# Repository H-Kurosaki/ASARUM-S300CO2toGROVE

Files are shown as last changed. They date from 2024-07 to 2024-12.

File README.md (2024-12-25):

# ASARUM-S300CO2toGROVE
ELT社のCO2センサS-300をGroveコネクタに対応させる基板のデータを公開しています。
boardall

◯公開しているデータの内容

/main/GerberData

Grove化基板のガーバーデータ、FusionPCBのファイル名に準拠しています。このフォルダの内容をzipに圧縮すればそのまま発注に使えます。

/main/EagleBoard

Eagle形式のPCBデータ(GerberDataの元データ)

/main/EagleLbr

Eagle形式のライブラリS-300のフットプリント。背面のJ11,J12コネクタのみ配置してあります。おまけでK30のフットプリントも入っていますが検証していません。

/main/BOM

実装部品表

/main/ArduinoS300test

Arduino UNO R3を用いた場合のテストプログラム。I2C接続時の読み出し試験。

◯基板の仕様

S-300のI2CインターフェースをGroveケーブルで引き出すことができます。
S-300の裏側の2mmピッチコネクタを使用するので基板から簡単にセンサを着脱できる実装が行えます。
MCDL校正を行う場合は通電して起動後に10分間MCDLと書かれた部分のピンをジャンパーで短絡してください。
その他I2C以外のピンもよく使いそうなものはピンヘッダに出ています。

基板の穴の間隔は未来工業社のウォルボックスWB-DMシリーズなどの穴の位置に合わせてあります。

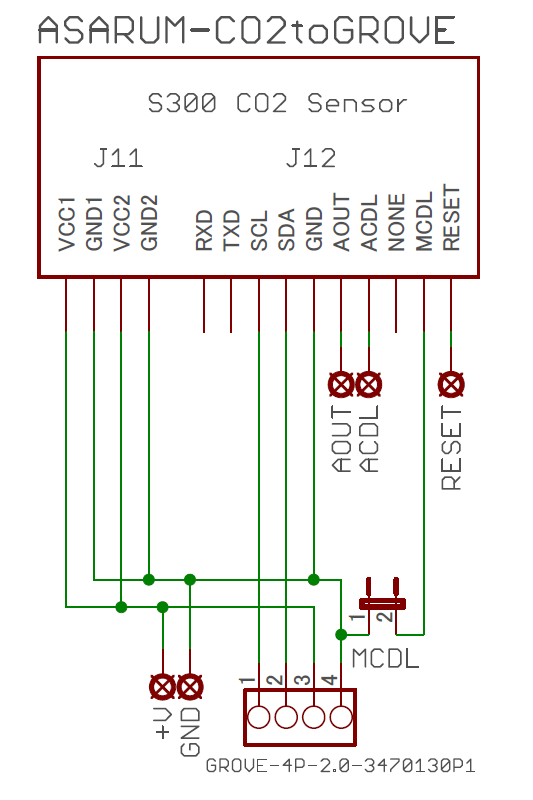
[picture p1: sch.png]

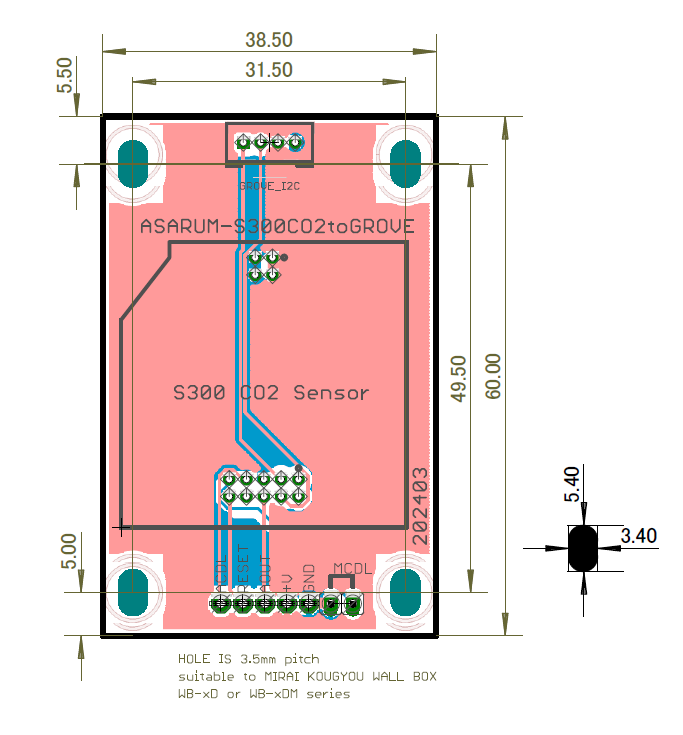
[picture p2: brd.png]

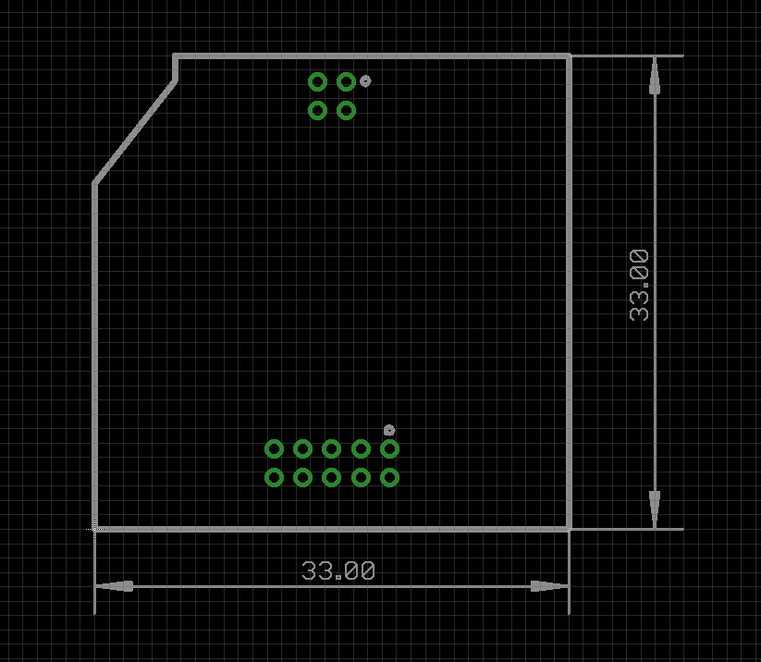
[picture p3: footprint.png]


◯使用上の注意とライセンス

本リポジトリで公開しているデータはELT社の公式なものではありません。
本リポジトリでライセンスを設定可能なファイルにはMITライセンスを適用させていただきます。
二次配布、商用利用も可能なデータとして配布しますが、本データを使用したことによって生じた結果については利用者が全ての責任を負うものとします。

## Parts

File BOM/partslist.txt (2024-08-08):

部品名	入手先	
Groveコネクター L型 スルーホール	https://akizukidenshi.com/catalog/g/g112634/	
コネクター付コード 4P 黒赤白黄 Grove用ケーブル	https://akizukidenshi.com/catalog/g/g116938/	
2mmピッチピンヘッダー 2×40 (80P)	https://akizukidenshi.com/catalog/g/g106075/	
ピンヘッダー 1×40 (40P)	https://akizukidenshi.com/catalog/g/g100167/	
つまみ付ジャンパーピン(黒)(2.54mmピッチ)	https://akizukidenshi.com/catalog/g/g103890/	(MCDL校正に使う)
		
※ピンヘッダは折って使います		
※Groveコネクターはスルーホール用であればL型(SEEED-110990037)も普通の直立型(SEEED-110990030)も両方使えます		
※ケーブルはあまり長くしないことを推奨します

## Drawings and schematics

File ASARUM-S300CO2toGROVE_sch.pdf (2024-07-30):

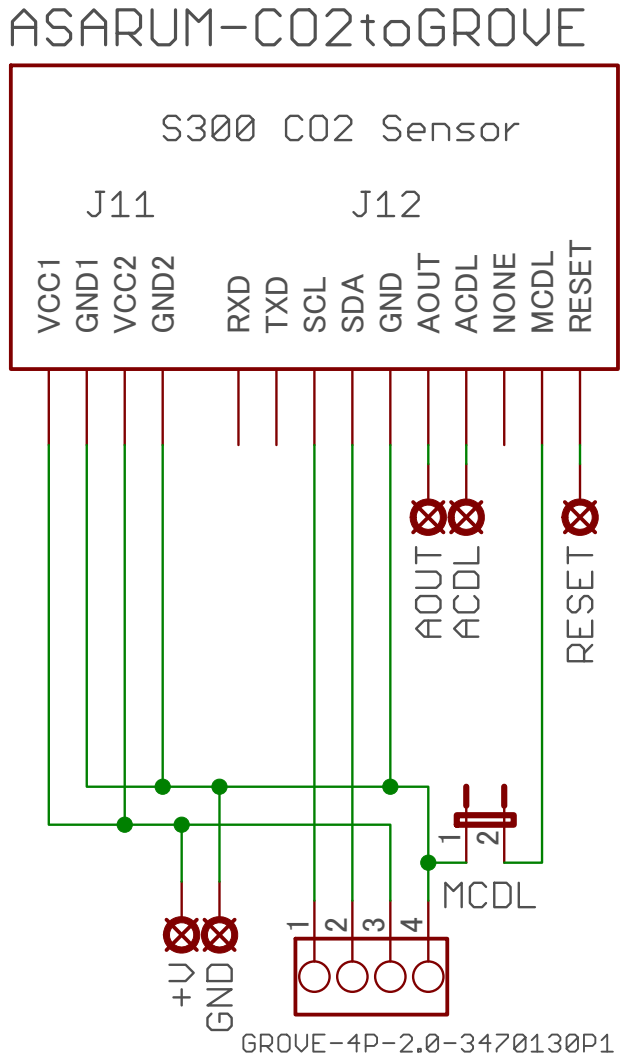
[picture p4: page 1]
VCC1; GND1; VCC2; GND2; RXD; TXD; SCL; SDA; GND; AOUT; ACDL; NONE; MCDL; RESET

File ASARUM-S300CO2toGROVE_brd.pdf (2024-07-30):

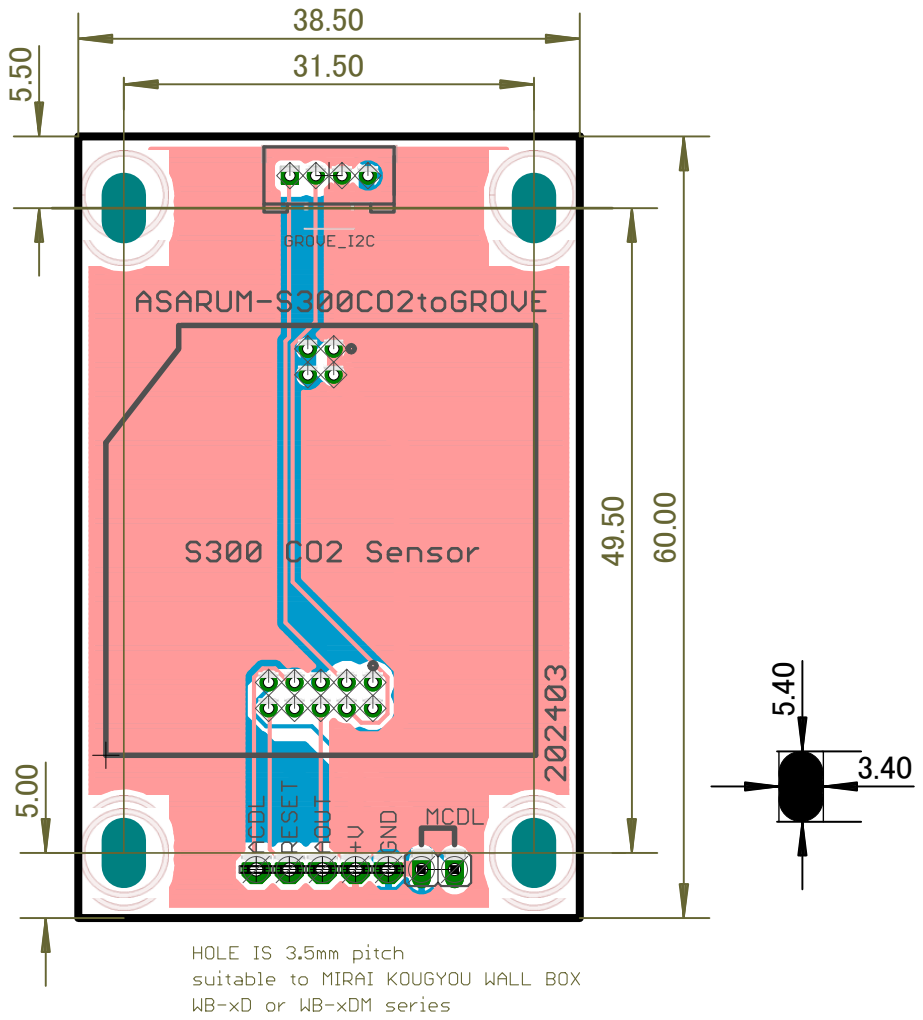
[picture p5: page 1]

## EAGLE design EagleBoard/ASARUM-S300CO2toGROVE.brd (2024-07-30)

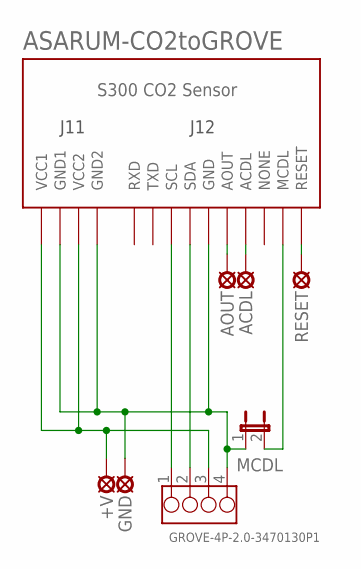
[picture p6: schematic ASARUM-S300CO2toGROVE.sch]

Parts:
+V: LSP10
ACDL: LSP10
AOUT: LSP10
GND: LSP10
GROVE_I2C: GROVE-4P-2.0-3470130P1; 4P-2.0
MCDL: JP1E; JP1
RESET: LSP10
S300: S300; S300REV

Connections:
GND: GND.MP, GROVE_I2C.4, MCDL.1, S300.J11P$2_GND (GND1), S300.J11P$4_GND (GND2), S300.J12P$5_GND (GND)
unnamed: GROVE_I2C.1, S300.J12P$3_SCL (SCL)
unnamed: GROVE_I2C.2, S300.J12P$4_SDA (SDA)
unnamed: MCDL.2, S300.J12P$9_MCDL (MCDL)
unnamed: RESET.MP, S300.J12P$10_RESET (RESET)
unnamed: ACDL.MP, S300.J12P$7_ACDL (ACDL)
unnamed: AOUT.MP, S300.J12P$6_AOUT (AOUT)
VCC: +V.MP, GROVE_I2C.3, S300.J11P$1_VCC (VCC1), S300.J11P$3_VCC (VCC2)

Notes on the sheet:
ASARUM-CO2toGROVE

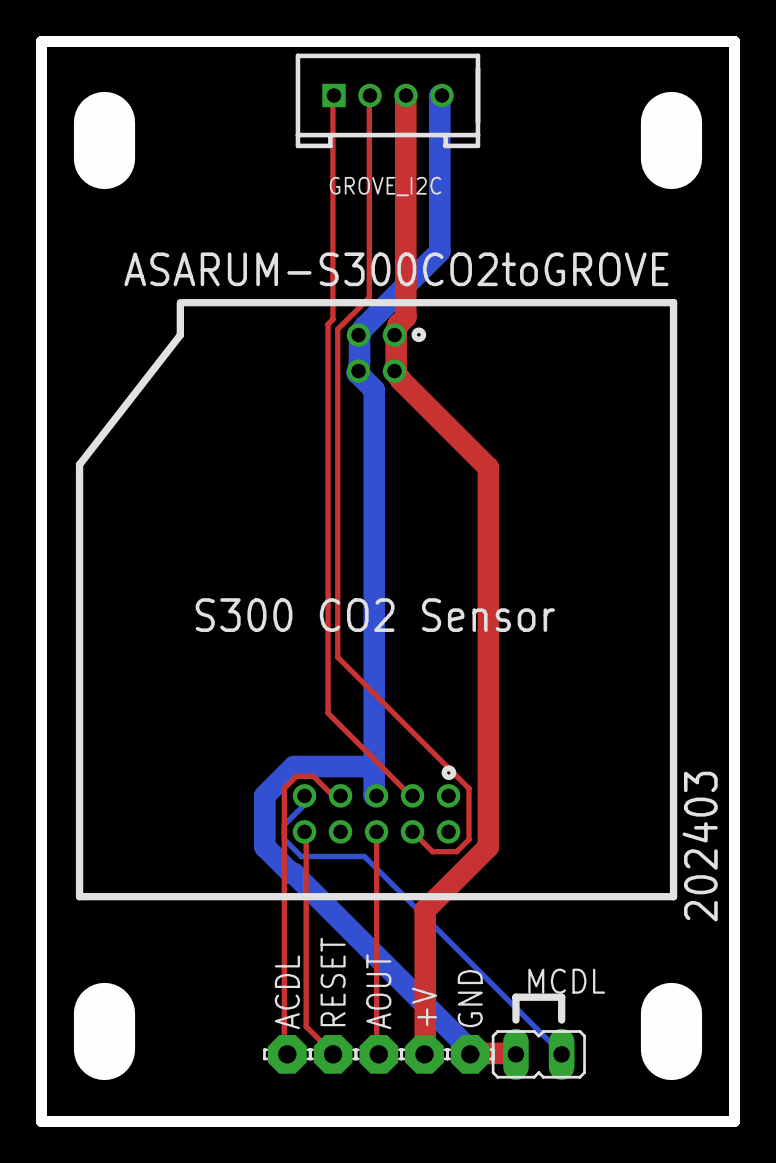
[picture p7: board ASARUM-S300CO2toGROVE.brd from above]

Board: 2 copper layers, 38.5 x 60.0 mm, 8 parts (0 on the bottom side), 8 nets.

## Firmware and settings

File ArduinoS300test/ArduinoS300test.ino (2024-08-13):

//for Arduino UNO or MEGA R3
//S-300 I2C test program
//s300i2c.h can get from https://github.com/mhorimoto/ELT_S300_HOLLY

#include "s300i2c.h"
#include <Wire.h>
S300I2C s3(Wire);

void setup() {
  Serial.begin(9600);
  Wire.begin();
  s3.begin(S300I2C_ADDR);
  delay(3000);
  Serial.println("START S300I2C");
}

void loop() {
  unsigned int co2;
  co2 = s3.getCO2ppm();
  Serial.print("CO2=");
  Serial.println(co2);
  delay(3000);
}
